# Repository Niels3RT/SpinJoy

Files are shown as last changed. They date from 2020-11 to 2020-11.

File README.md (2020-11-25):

# SpinJoy - Spinner and Joystick combo

## Introduction
It's a spinner/joystick combo device based on [Sorgeligs PaddleTwoControllersUSB project](https://github.com/MiSTer-devel/Retro-Controllers-USB-MiSTer/tree/master/PaddleTwoControllersUSB) in a single Arduino Pro Micro (ATmega32U4) board.

The Arduino shows up as 2 devices, a digital joystick+12 buttons with added wheel+dial and a mouse that moves the x/y axes by rotating the spinner. This works nicely with Mister and was tested on Arkanoid and Block Gal cores.

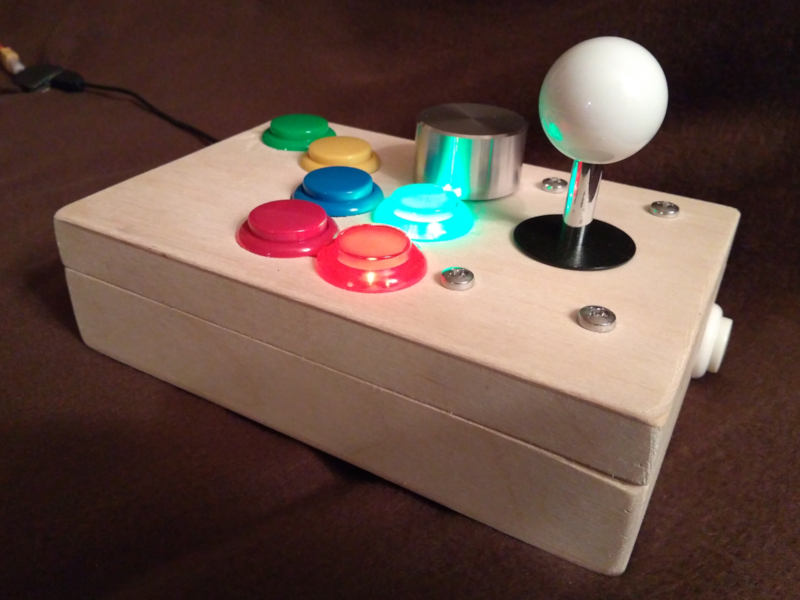
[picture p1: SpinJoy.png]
SpinJoy


### Spinner
You can use almost any 2-phase spinner. Hight-PPR (300+) spinners provide more smooth scroll while even simple miniature Arduino shield spinner with 20PPR is fine.
I used a WISAMIC 600p/r Incremental Rotary Encoder DC5-24v as cheaply sold on EBay, AliExpress or Amazon.

### Joystick/Buttons
There are many Arcade Joystick/Button sets available on EBay, AliExpress or Amazon.
I bought the cheapest, any other should work too.

### Connecting/Assembling

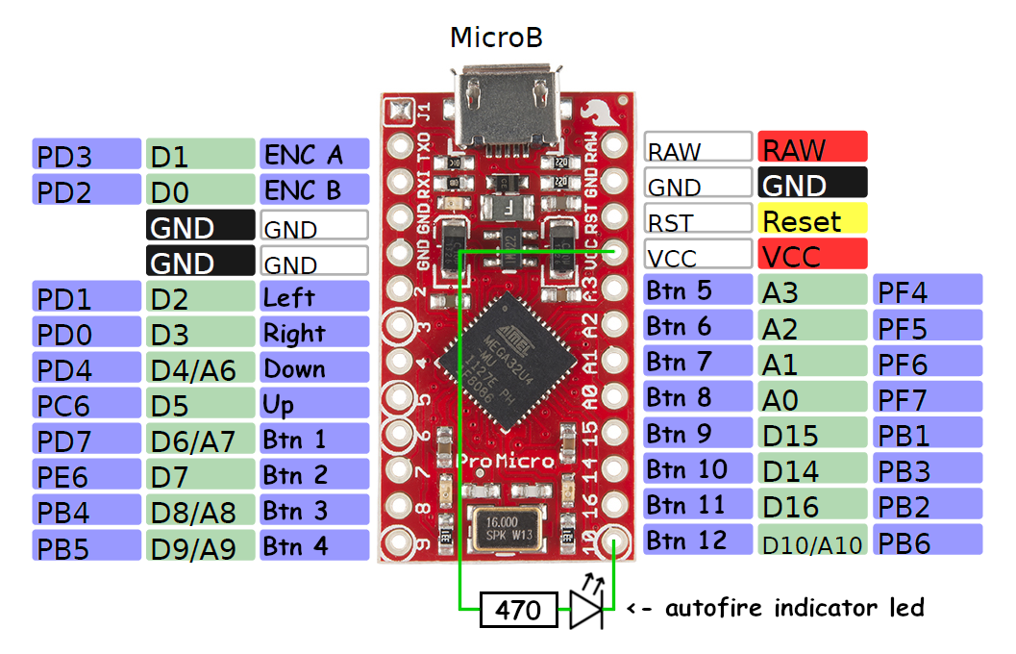
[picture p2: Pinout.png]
Arduino Pro Micro Pinout


Rotary encoder:
| Wire Color | Function |
|---|---|
| red | 5v |
| black | gnd |
| white | Enc A |
| green | Enc B |

The ribbon cable for the joystick fits nicely to pin headers soldered to the Arduino, the cables to the buttons fit pin headers too:
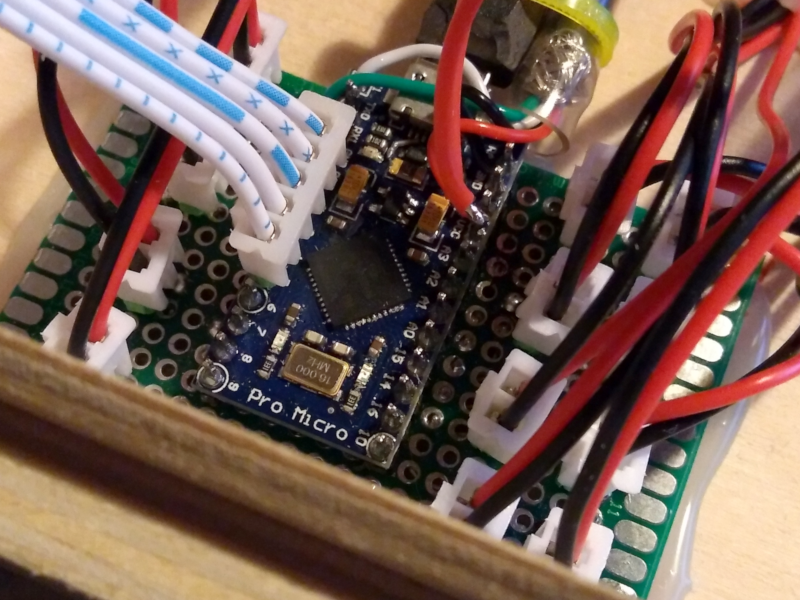
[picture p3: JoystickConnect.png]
Arduino Joystick connector


### Source parameters
Firmware has several definitions to tweak for best experience:

1. SPINNER_PPR: set the correct PPR value according to your spinner for correct work.
2. DEBOUNCE_TOP: a counter is used to debounce buttons and stick movement. Set to 1 to completely disable debouncing. The switches in my (cheeaaap) joystick/button set need a value of 32 to stop bouncing, your mileage may vary. The menus in Mister scripts seem to be a good place to test this. This counter is only applied to switch release to minimize lag.
3. USE_AUTOFIRE: comment to disable autofire function, buttons 11/12 are reported via USB in any case.
4. AUTOFIRE_TUNE_FACTOR: bigger number -> faster autofire rate modification, lower number -> finer adjustment, default is 4

### Autofire
Autofire for button 1 is enabled by pushing button 12 (as long as its down), if you plan to use it its a good idea to connect a switch there.

To modify the fire rate hold down button 11 and use the spinner. The new rate is saved to eeprom when button 11 is released.

### Drill Template
There is a simple drill template included for mounting the rotary encoder and the joystick. Please verify the dimensions of the printed PDF before drilling, its for A4 paper size and scaling may be involved in printing.
A DXF file is also included to move things around in LibreCAD.

## License
This project is licensed under the GNU General Public License v3.0.

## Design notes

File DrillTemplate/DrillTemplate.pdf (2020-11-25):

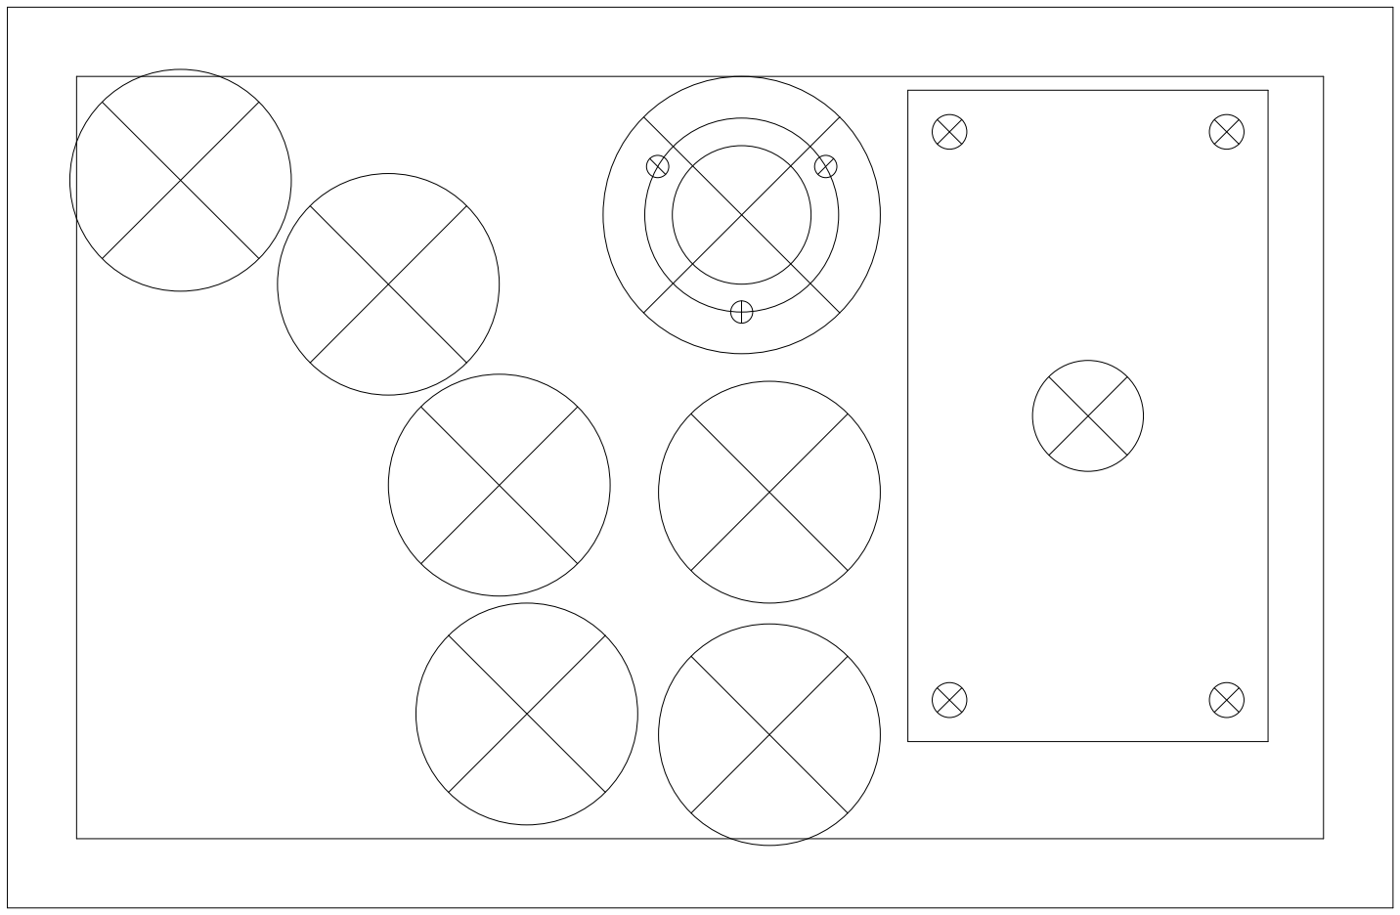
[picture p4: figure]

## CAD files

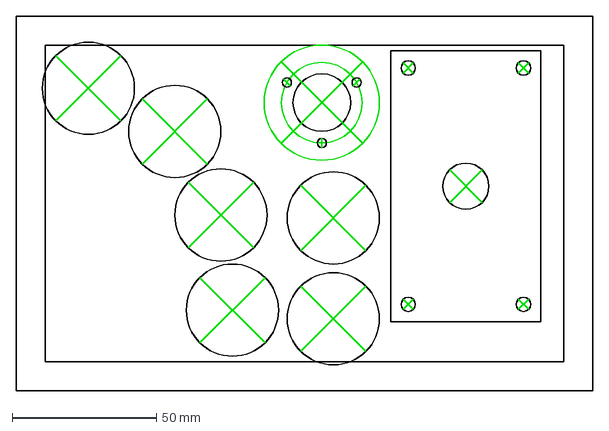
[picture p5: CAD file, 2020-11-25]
DrillTemplate/JoyCAD.dxf
200.0 x 130.0 mm

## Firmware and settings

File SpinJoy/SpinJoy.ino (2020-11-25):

/*
    A2600 Paddles/Spinners USB Adapter
    (C) Alexey Melnikov

    Based on project by Mikael Norrgård <mick@daemonbite.com>

    GNU GENERAL PUBLIC LICENSE
    Version 3, 29 June 2007

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
*/

///////////////// Customizable settings /////////////////////////

// Spinner pulses per revolution
// For arduino shield spinner: 20
//#define SPINNER_PPR 20
#define SPINNER_PPR 600

// upper limit for debounce counter
// set to 1 to disable debouncing
// 16 seems ok, but sometimes still bounces on my setup
#define DEBOUNCE_TOP 32

// comment to disable autofire
#define USE_AUTOFIRE

// autofire tuning rate/spped, factor encoder rate to autofire rate
#define AUTOFIRE_TUNE_FACTOR 4

///////////////// a shortcut ////////////////////////////////////

#define cbi(sfr, bit)     (_SFR_BYTE(sfr) &= ~_BV(bit))
#define sbi(sfr, bit)     (_SFR_BYTE(sfr) |= _BV(bit))

/////////////////////////////////////////////////////////////////

// pins map
const int8_t encpin[2] = {1, 0};        // rotary encoder

////////////////////////////////////////////////////////

#ifndef SPINNER_SENSITIVITY
#if SPINNER_PPR < 50
#define SPINNER_SENSITIVITY 1
#else
#define SPINNER_SENSITIVITY 2
#endif
#endif

// ID for special support in MiSTer
// ATT: 20 chars max (including NULL at the end) according to Arduino source code.
// Additionally serial number is used to differentiate arduino projects to have different button maps!
//const char *gp_serial_spin = "MiSTer-S1 Spinner";
const char *gp_serial = "SpinJoy V0.1";

#include <EEPROM.h>
#include "Joystick.h"
#include "Mouse.h"

Joystick_ Joystick;
SMouse_ SMouse;

uint8_t cnt_stick[4] = { DEBOUNCE_TOP, DEBOUNCE_TOP, DEBOUNCE_TOP, DEBOUNCE_TOP };
uint8_t cnt_btn[12]  = { DEBOUNCE_TOP, DEBOUNCE_TOP, DEBOUNCE_TOP, DEBOUNCE_TOP,
                         DEBOUNCE_TOP, DEBOUNCE_TOP, DEBOUNCE_TOP, DEBOUNCE_TOP,
                         DEBOUNCE_TOP, DEBOUNCE_TOP, DEBOUNCE_TOP, DEBOUNCE_TOP };

uint16_t drvpos;

#ifdef USE_AUTOFIRE
  uint16_t auto_cnt = 0;
  uint16_t auto_max = 1000;
  uint16_t auto_state = 0x001;
  bool auto_modify = false;
#endif

#define SP_MAX ((SPINNER_PPR*4*270UL)/360)
const uint16_t sp_max = SP_MAX;
int32_t sp_clamp = SP_MAX / 2;

void drv_proc(void)
{
  static int8_t prev;
  int8_t a = digitalRead(encpin[0]);
  int8_t b = digitalRead(encpin[1]);

  int8_t spval = (b << 1) | (b ^ a);
  int8_t diff = (prev - spval) & 3;

  if (diff == 1)
  {
    drvpos += 10;
    if (sp_clamp < sp_max) sp_clamp++;
  }
  if (diff == 3)
  {
    drvpos -= 10;
    if (sp_clamp > 0) sp_clamp--;
  }

  prev = spval;
}

void drv0_isr()
{
  drv_proc();
}

void drv1_isr()
{
  drv_proc();
}

void setup()
{
  float snap = .01;
  float thresh = 8.0;

  // set all usable pins to input with pullups
  DDRB  &= ~B01111110;
  PORTB |=  B01111110;
  DDRC  &= ~B01000000;
  PORTC |=  B01000000;
  DDRD  &= ~B10011111;
  PORTD |=  B10011111;
  DDRE  &= ~B01000000;
  PORTE |=  B01000000;
  DDRF  &= ~B11110000;
  PORTF |=  B11110000;

  Joystick.reset();
  SMouse.reset();

  drv_proc();
  drvpos = 0;
  attachInterrupt(digitalPinToInterrupt(encpin[0]), drv0_isr, CHANGE);
  attachInterrupt(digitalPinToInterrupt(encpin[1]), drv0_isr, CHANGE);

#ifdef USE_AUTOFIRE
  // read auto_max from eeprom
  ee_auto_max_read();
#endif
}

JoystickReport joy_rep;
SMouseReport mouse_rep;
const int16_t sp_step = (SPINNER_PPR * 10) / (20 * SPINNER_SENSITIVITY);
void loop()
{
  // LEDs off
  TXLED1; //RXLED1;

  // paddle emulation
  joy_rep.paddle = ((sp_clamp * 255) / sp_max);

  // spinner/wheel rotation
  static uint16_t prev = 0;
  int16_t val = ((int16_t)(drvpos - prev)) / sp_step;
  if (val > 127) val = 127; else if (val < -127) val = -127;
  joy_rep.spinner = val;
  prev += val * sp_step;

  ////// joystick //////
  joy_rep.buttons = 0x000;

  // joystick buttons
  if (!(PIND & (1 << PD7))) cnt_btn[0]  = 0; else if (cnt_btn[0]  < DEBOUNCE_TOP) cnt_btn[0]++;
  if (!(PINE & (1 << PE6))) cnt_btn[1]  = 0; else if (cnt_btn[1]  < DEBOUNCE_TOP) cnt_btn[1]++;
  if (!(PINB & (1 << PB4))) cnt_btn[2]  = 0; else if (cnt_btn[2]  < DEBOUNCE_TOP) cnt_btn[2]++;
  if (!(PINB & (1 << PB5))) cnt_btn[3]  = 0; else if (cnt_btn[3]  < DEBOUNCE_TOP) cnt_btn[3]++;
  if (!(PINF & (1 << PF4))) cnt_btn[4]  = 0; else if (cnt_btn[4]  < DEBOUNCE_TOP) cnt_btn[4]++;
  if (!(PINF & (1 << PF5))) cnt_btn[5]  = 0; else if (cnt_btn[5]  < DEBOUNCE_TOP) cnt_btn[5]++;
  if (!(PINF & (1 << PF6))) cnt_btn[6]  = 0; else if (cnt_btn[6]  < DEBOUNCE_TOP) cnt_btn[6]++;
  if (!(PINF & (1 << PF7))) cnt_btn[7]  = 0; else if (cnt_btn[7]  < DEBOUNCE_TOP) cnt_btn[7]++;
  if (!(PINB & (1 << PB1))) cnt_btn[8]  = 0; else if (cnt_btn[8]  < DEBOUNCE_TOP) cnt_btn[8]++;
  if (!(PINB & (1 << PB3))) cnt_btn[9]  = 0; else if (cnt_btn[9]  < DEBOUNCE_TOP) cnt_btn[9]++;
  if (!(PINB & (1 << PB2))) cnt_btn[10] = 0; else if (cnt_btn[10] < DEBOUNCE_TOP) cnt_btn[10]++;
  if (!(PINB & (1 << PB6))) cnt_btn[11] = 0; else if (cnt_btn[11] < DEBOUNCE_TOP) cnt_btn[11]++;
  // buttons 1 to 11
  for (uint8_t i=1;i<12;i++) {
    joy_rep.buttons >>= 1;
    if (cnt_btn[i] < DEBOUNCE_TOP) joy_rep.buttons |= 0x800;
  }
#ifndef USE_AUTOFIRE
  if (cnt_btn[0] < DEBOUNCE_TOP) joy_rep.buttons |= 0x001;
#else
  // button 0, autofire
  if (cnt_btn[0] < DEBOUNCE_TOP) {
    // autfire active if button 11 is pressed/switched
    if (cnt_btn[11] < DEBOUNCE_TOP) {
      // autofire
      if (auto_cnt < auto_max) {
        auto_cnt++;
        joy_rep.buttons |= auto_state;
      } else {
        auto_cnt = 0;
        auto_state ^= 0x001;
      }
    } else {
      // single fire
      joy_rep.buttons |= 0x001;
    }
  } else {
    auto_cnt = 0;
    auto_state = 0x001;
  }
  // modify autofire frequencey? must be active and button 10 be pressed
  if ((cnt_btn[10] < DEBOUNCE_TOP) && (cnt_btn[11] < DEBOUNCE_TOP)) {
    auto_modify = true;
    auto_max += (val * AUTOFIRE_TUNE_FACTOR);
    if (auto_max < 400) auto_max = 400;
    if (auto_max > 60000) auto_max = 60000;
  } else {
    if (auto_modify) {
      auto_modify = false;
      ee_auto_max_update();
    }
  }
#endif

  // joystick directions
  if (!(PINC & (1 << PC6))) cnt_stick[0] = 0; else if (cnt_stick[0] < DEBOUNCE_TOP) cnt_stick[0]++;     // up
  if (!(PIND & (1 << PD4))) cnt_stick[1] = 0; else if (cnt_stick[1] < DEBOUNCE_TOP) cnt_stick[1]++;     // down
  if (!(PIND & (1 << PD0))) cnt_stick[2] = 0; else if (cnt_stick[2] < DEBOUNCE_TOP) cnt_stick[2]++;     // right
  if (!(PIND & (1 << PD1))) cnt_stick[3] = 0; else if (cnt_stick[3] < DEBOUNCE_TOP) cnt_stick[3]++;     // left

  if (cnt_stick[0] < DEBOUNCE_TOP) joy_rep.y = -1; else if (cnt_stick[1] < DEBOUNCE_TOP) joy_rep.y = 1; else joy_rep.y = 0;   // up/down
  if (cnt_stick[3] < DEBOUNCE_TOP) joy_rep.x = -1; else if (cnt_stick[2] < DEBOUNCE_TOP) joy_rep.x = 1; else joy_rep.x = 0;   // left/right

  // Only report controller state if it has changed
  if (memcmp(&Joystick._JoystickReport, &joy_rep, sizeof(JoystickReport)))
  {
    Joystick._JoystickReport = joy_rep;
    Joystick.send();
  }

  ////// mouse //////
  mouse_rep.x = val;
  mouse_rep.y = val;

  // Only report controller state if it has changed
  if (memcmp(&SMouse._SMouseReport, &mouse_rep, sizeof(SMouseReport)))
  {
    SMouse._SMouseReport = mouse_rep;
    SMouse.send();
  }
}
#ifdef USE_AUTOFIRE
// read autofire max from eeprom
void ee_auto_max_read() {
  uint16_t a = ee_word_read(0x00);
  uint16_t b = ee_word_read(0x02) ^ 0xffff;
  uint16_t c = ee_word_read(0x04) ^ 0x4e4c;
  // compare
  if ((a == b) && (a == c)) {
    // read auto_max ok, use
    auto_max = a;
  } else {
    // read auto_max nok, use default and update eeprom
    auto_max = 1000;
    ee_auto_max_update();
  }
}

// write autofire max to eeprom
void ee_auto_max_update() {
  ee_word_update(0x00, auto_max);
  ee_word_update(0x02, auto_max ^ 0xffff);
  ee_word_update(0x04, auto_max ^ 0x4e4c);
}

// read 16bit word from eeprom
uint16_t ee_word_read(int adr) {
  uint16_t tword = 0;
  tword = (uint16_t)EEPROM.read(adr++) << 8;
  tword += EEPROM.read(adr);
  return (tword);
}
// update 16bit word in eeprom
void ee_word_update(int adr, uint16_t tword) {
  EEPROM.update(adr++, (tword>>8)&0xff);
  EEPROM.update(adr, tword&0xff);
}
#endif

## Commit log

2020-11-25 fix fire rate eeprom
    [SpinJoy.ino]
2020-11-25 add autofire led

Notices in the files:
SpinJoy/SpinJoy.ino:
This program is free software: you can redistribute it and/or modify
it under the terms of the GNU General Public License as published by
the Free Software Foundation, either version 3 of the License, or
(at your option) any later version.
